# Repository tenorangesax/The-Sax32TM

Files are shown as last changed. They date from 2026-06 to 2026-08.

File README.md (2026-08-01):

# The-Sax32TM
This is a simple devboard utilizing the ESP32-S3-WROOM-1 chip. Designed by me to really understand how the ESP32 works and all those little components on the front do, while also giving me a little more experience with creating devboards now.  (Being displayed at Opensauce!)

**[THE WORKING VIDEO DEMO!!](https://youtu.be/G2ZkvX7cIcQ)**

**FINAL SHOTS:**




**3D VIEWER:**
[Sax32 BOM.csv](https://github.com/user-attachments/files/30619961/Sax32.BOM.csv)




**THE SCHEMATIC:**



**PCB EDITOR:**

Screenshot 2026-06-14 at 10 48 29 AM

**BOM:**

| Id | Designator | Footprint | Quantity | Comment | Supplier and ref |
|---:|---|---|---:|---|---|
| 1 | BOOT, RST | SW_Push_SPST_NO_Alps_SKRK | 2 | SW_SPST |  |
| 2 | C1, C4 | C_0603_1608Metric | 2 | 100nf |  |
| 3 | C2, C5 | C_0603_1608Metric | 2 | 10uf |  |
| 4 | C3 | C_0603_1608Metric | 1 | 22uf |  |
| 5 | D1 | LED_0603_1608Metric | 1 | RED |  |
| 6 | D2 | LED_0603_1608Metric | 1 | GREEN |  |
| 7 | D3 | LED_0603_1608Metric | 1 | BLUE |  |
| 8 | J1, J2 | PinHeader_1x20_P2.54mm_Vertical | 2 | Conn_01x20_Pin |  |
| 9 | J3 | USB_C_Receptacle_HRO_TYPE-C-31-M-12 | 1 | USB_C_Receptacle_USB2.0_16P |  |
| 10 | R1, R2, R3, R4, R5, R6 | R_0603_1608Metric | 6 | 5.1k |  |
| 11 | U1 | SOT-223-3_TabPin2 | 1 | LD1117S33TR_SOT223 |  |
| 12 | U3 | ESP32-S3-WROOM-1 | 1 | ESP32-S3-WROOM-1 |  |

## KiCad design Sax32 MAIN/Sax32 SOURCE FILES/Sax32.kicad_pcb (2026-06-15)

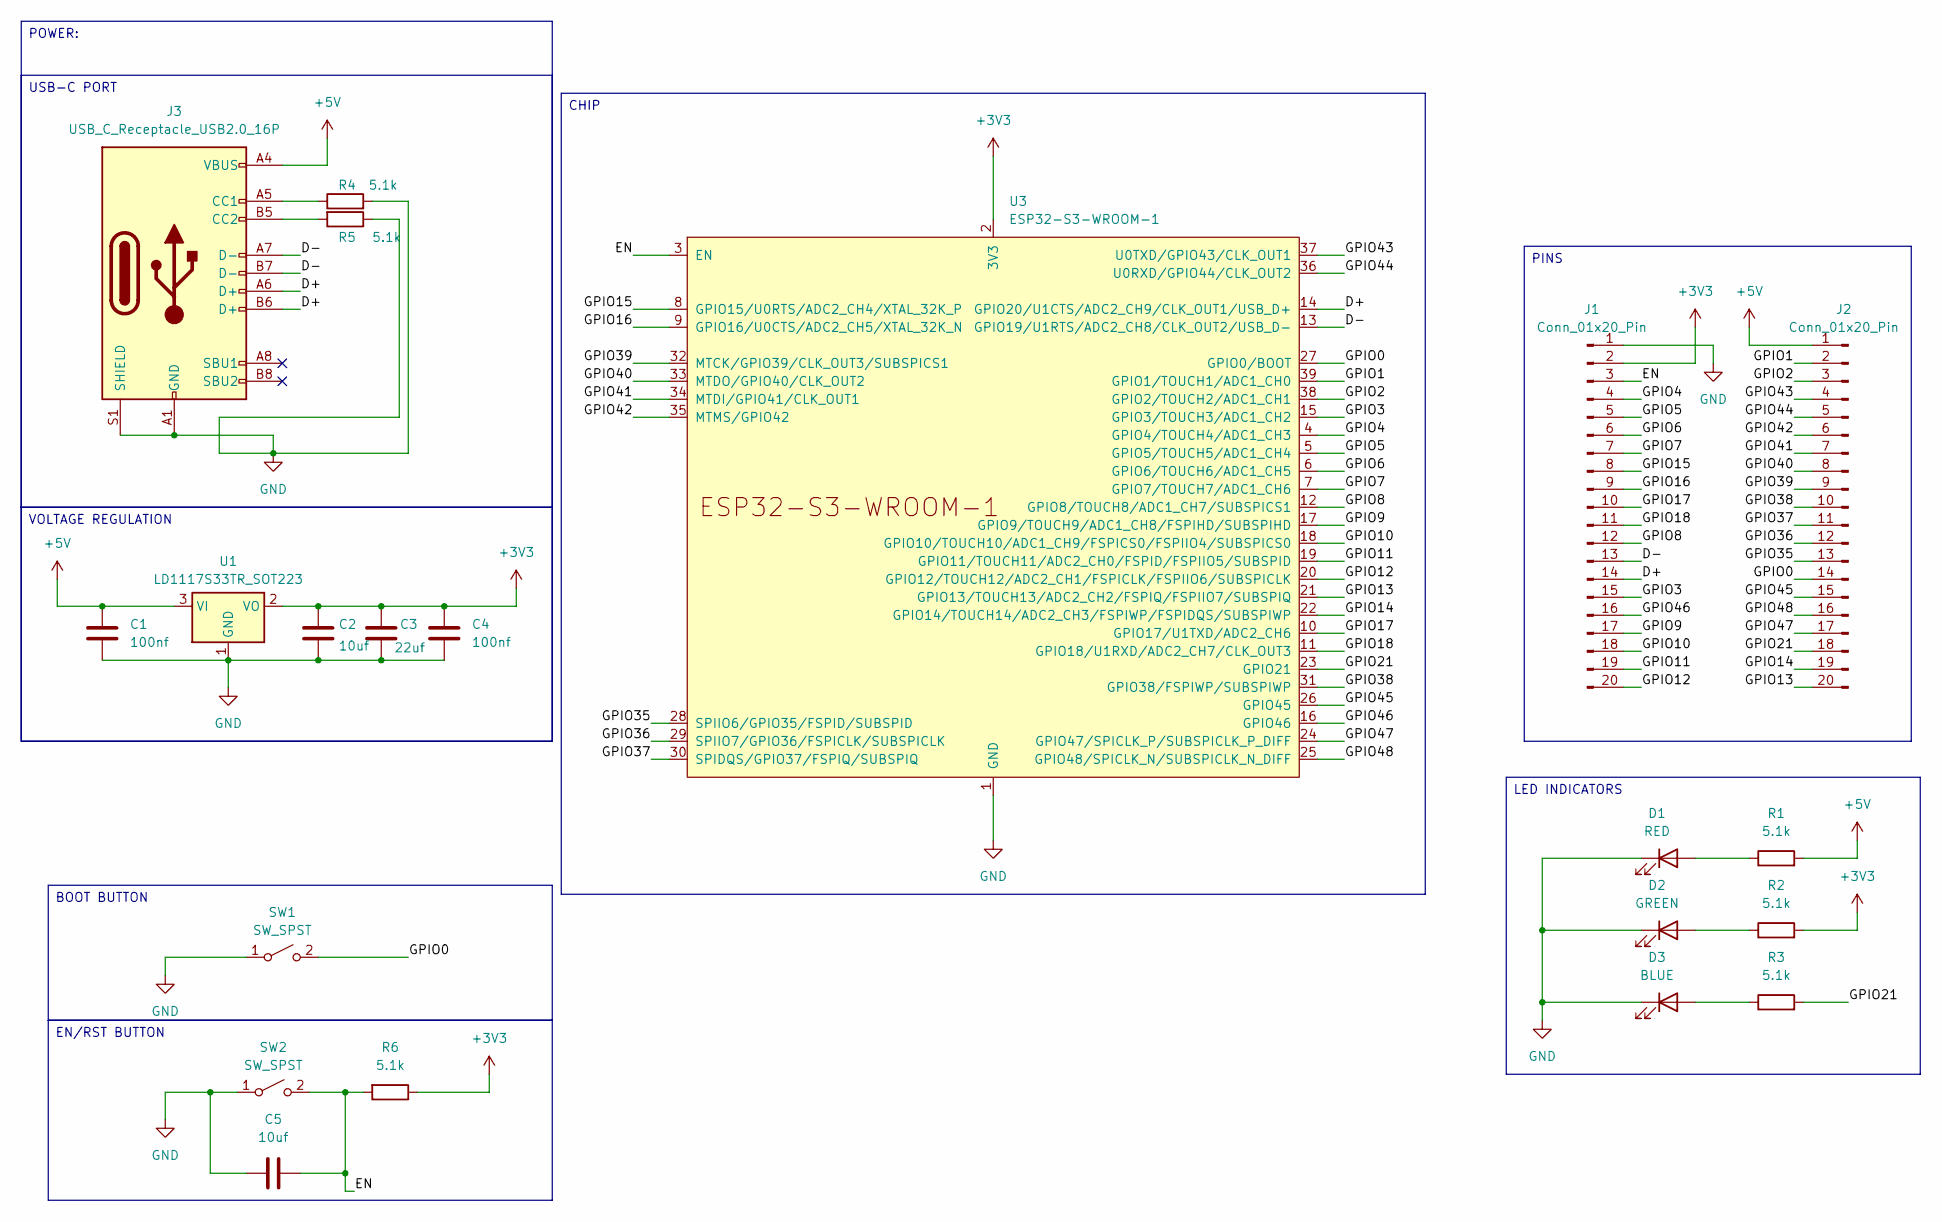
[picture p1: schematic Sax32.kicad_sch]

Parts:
C1, C4: 100nf; C_0603_1608Metric
C2, C5: 10uf; C_0603_1608Metric
C3: 22uf; C_0603_1608Metric
D1: RED; LED_0603_1608Metric
D2: GREEN; LED_0603_1608Metric
D3: BLUE; LED_0603_1608Metric
J1, J2: Conn_01x20_Pin; PinHeader_1x20_P2.54mm_Vertical
J3: USB_C_Receptacle_USB2.0_16P; USB_C_Receptacle_HRO_TYPE-C-31-M-12
R1, R2, R3, R4, R5, R6: 5.1k; R_0603_1608Metric
SW1, SW2: SW_SPST; SW_Push_SPST_NO_Alps_SKRK
U1: LD1117S33TR_SOT223; SOT-223-3_TabPin2
U3: ESP32-S3-WROOM-1

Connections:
+3V3: C2.1, C3.1, C4.1, J1.2, R2.2, R6.1, U1.2 (VO), U3.2 (3V3)
+5V: C1.1, J2.1, J3.A4 (VBUS), J3.A9 (VBUS), J3.B4 (VBUS), J3.B9 (VBUS), R1.2, U1.3 (VI)
/D+: J1.14, J3.A6 (D+), J3.B6 (D+), U3.14 (GPIO20/U1CTS/ADC2_CH9/CLK_OUT1/USB_D+)
/D-: J1.13, J3.A7 (D-), J3.B7 (D-), U3.13 (GPIO19/U1RTS/ADC2_CH8/CLK_OUT2/USB_D-)
/EN: C5.2, J1.3, R6.2, SW2.2 (B), U3.3 (EN); also elsewhere on the board
/GPIO0: J2.14, SW1.2 (B), U3.27 (GPIO0/BOOT); also elsewhere on the board
/GPIO1: J2.2, U3.39 (GPIO1/TOUCH1/ADC1_CH0)
/GPIO2: J2.3, U3.38 (GPIO2/TOUCH2/ADC1_CH1)
/GPIO3: J1.15, U3.15 (GPIO3/TOUCH3/ADC1_CH2)
/GPIO4: J1.4, U3.4 (GPIO4/TOUCH4/ADC1_CH3)
/GPIO5: J1.5, U3.5 (GPIO5/TOUCH5/ADC1_CH4)
/GPIO6: J1.6, U3.6 (GPIO6/TOUCH6/ADC1_CH5)
/GPIO7: J1.7, U3.7 (GPIO7/TOUCH7/ADC1_CH6)
/GPIO8: J1.12, U3.12 (GPIO8/TOUCH8/ADC1_CH7/SUBSPICS1)
/GPIO9: J1.17, U3.17 (GPIO9/TOUCH9/ADC1_CH8/FSPIHD/SUBSPIHD)
/GPIO10: J1.18, U3.18 (GPIO10/TOUCH10/ADC1_CH9/FSPICS0/FSPIIO4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)
/GPIO11: J1.19, U3.19 (GPIO11/TOUCH11/ADC2_CH0/FSPID/FSPIIO5/S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)
/GPIO12: J1.20, U3.20 (GPIO12/TOUCH12/ADC2_CH1/FSPICLK/FSPIIO6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)
/GPIO13: J2.20, U3.21 (GPIO13/TOUCH13/ADC2_CH2/FSPIQ/FSPIIO7/S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)
/GPIO14: J2.19, U3.22 (GPIO14/TOUCH14/ADC2_CH3/FSPIWP/FSPIDQS/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)
/GPIO15: J1.8, U3.8 (GPIO15/U0RTS/ADC2_CH4/XTAL_32K_P)
/GPIO16: J1.9, U3.9 (GPIO16/U0CTS/ADC2_CH5/XTAL_32K_N)
/GPIO17: J1.10, U3.10 (GPIO17/U1TXD/ADC2_CH6)
/GPIO18: J1.11, U3.11 (GPIO18/U1RXD/ADC2_CH7/CLK_OUT3)
/GPIO21: J2.18, R3.2, U3.23 (GPIO21)
/GPIO35: J2.13, U3.28 (SPIIO6/GPIO35/FSPID/SUBSPID)
/GPIO36: J2.12, U3.29 (SPIIO7/GPIO36/FSPICLK/SUBSPICLK)
/GPIO37: J2.11, U3.30 (SPIDQS/GPIO37/FSPIQ/SUBSPIQ)
/GPIO38: J2.10, U3.31 (GPIO38/FSPIWP/SUBSPIWP)
/GPIO39: J2.9, U3.32 (MTCK/GPIO39/CLK_OUT3/SUBSPICS1)
/GPIO40: J2.8, U3.33 (MTDO/GPIO40/CLK_OUT2)
/GPIO41: J2.7, U3.34 (MTDI/GPIO41/CLK_OUT1)
/GPIO42: J2.6, U3.35 (MTMS/GPIO42)
/GPIO43: J2.4, U3.37 (U0TXD/GPIO43/CLK_OUT1)
/GPIO44: J2.5, U3.36 (U0RXD/GPIO44/CLK_OUT2)
/GPIO45: J2.15, U3.26 (GPIO45)
/GPIO46: J1.16, U3.16 (GPIO46)
/GPIO47: J2.17, U3.24 (GPIO47/SPICLK_P/SUBSPICLK_P_DIFF)
/GPIO48: J2.16, U3.25 (GPIO48/SPICLK_N/SUBSPICLK_N_DIFF)
GND: C1.2, C2.2, C3.2, C4.2, C5.1, D1.1 (K), D2.1 (K), D3.1 (K), J1.1, J3.A1 (GND), J3.A12 (GND), J3.B1 (GND), J3.B12 (GND), J3.S1 (SHIELD), R4.2, R5.1, SW1.1 (A), SW2.1 (A), U1.1 (GND), U3.1 (GND), U3.40 (GND), U3.41 (GND); also elsewhere on the board
unnamed: D1.2 (A), R1.1
unnamed: D2.2 (A), R2.1
unnamed: D3.2 (A), R3.1
unnamed: J3.A5 (CC1), R4.1
unnamed: J3.B5 (CC2), R5.2

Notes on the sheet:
VOLTAGE REGULATION
PINS
POWER:
EN/RST BUTTON
LED INDICATORS
USB-C PORT
BOOT BUTTON
CHIP

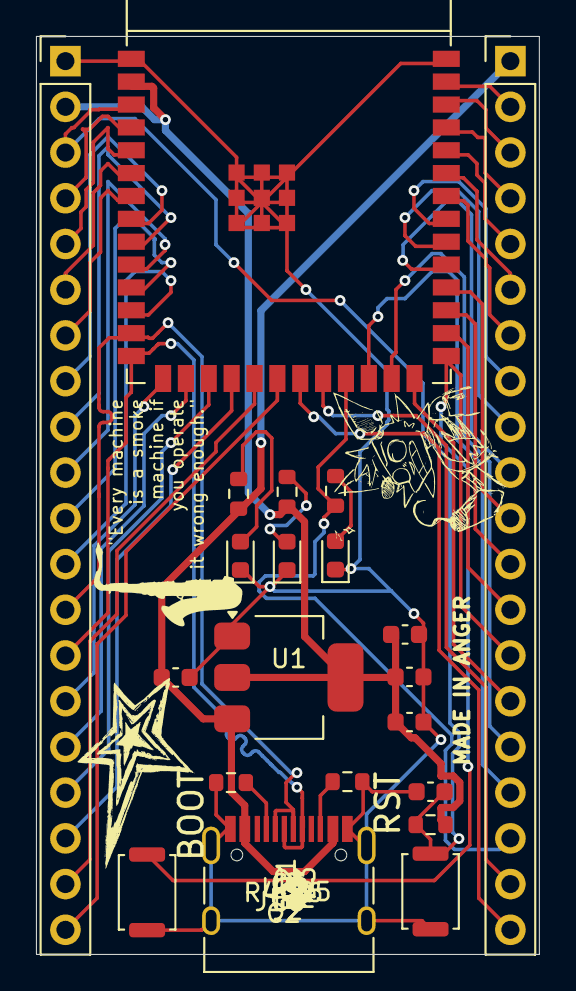
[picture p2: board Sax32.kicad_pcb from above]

Board: 2 copper layers, 27.9 x 51.0 mm, 21 parts (0 on the bottom side), 45 nets.

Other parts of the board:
BOOT: SW_SPST; SW_Push_SPST_NO_Alps_SKRK
RST: SW_SPST; SW_Push_SPST_NO_Alps_SKRK

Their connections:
/EN: RST.2 (B); also elsewhere on the board
/GPIO0: BOOT.2 (B); also elsewhere on the board
GND: BOOT.1 (A), RST.1 (A); also elsewhere on the board

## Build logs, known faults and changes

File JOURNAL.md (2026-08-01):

<!--
  This journal is auto generated by Stasis.
-->

# 7/12/2026 4 PM - SOLDERING AND FINISHING TOUCHES!

_Time spent: 3.5h_

My stuff finally arrived, so I could get to work! (at least most of them)

The devboard, S3 chips, (buttons I already had from previous projects) were here!

I did order a hotplate and some solder paste because in the center, there are these ground pins that I asked about, and apparently they are used
for cooling the chip.

While my hotplate wasn't there, I decided to hand solder a chip and buttons to see how it would go.

It was a little hard, but I got the hang of it and it became fun!

It also worked and I put thonny firmware on it.

When my hotplate did arrive though, I broke the stencil because my board was already populated with components, and i just needed the chip stencil to lay flat on the board.

Unfortuantely it didn't work and smeared all over the pins, so i just decided to put a glob all over it since the flux would guide it to the pads, which did work after I adjusted
the solder on the hot plate while it cooked.



Those boards also worked too, which was a success! I tested in thonny after.






































# 6/15/2026 2 AM - FINISHING UP AND REVIEWER SENDING TIME!!!

_Time spent: 2.75h_

Today I finished up the entire ordering process, and made sure to be able to get a good cost on everything to make it as cheap as possible.

Firstly, I put whatever I could in the PCBA assembly, mainly the LEDS, capacitors, resistors because I didn't want to do those tiny little connections, and had to find where the cheapest options were and making sure that they were the correct voltage and stuff.

The LEDS had to be comprimised, and I had to make 2 of them red and one white so I could do economic PCBA assembly for a low price.

In the 3D editor, I adjusted the parts, like the 1117 and USBC port and others to their correct positons/polarity.

I then had to find where the source of the ESP32-S3-WROOM-1-N16R2 Modules were being sold, got the amazon link after digging through the entire website, and added to cart.

The push buttons I already have at home from my last devboard, and I made sure to use the same footprint so I could cut costs.

I then set up the github and sent it on its way! 

Screenshot 2026-06-14 at 9.08.30 PM

Screenshot 2026-06-14 at 9.08.20 PM

Screenshot 2026-06-14 at 9.05.34 PM

Screenshot 2026-06-14 at 9.46.15 PM

Screenshot 2026-06-14 at 9.30.22 PM

I also got a stencil to solder it







# 6/14/2026 7 PM - PCB Design Finish

_Time spent: 5.75h_

First off, I assigned the footprints:

Screenshot 2026-06-13 at 6.50.39 PM

Obviously all SMD components and turtle buttons, with the same USBC port I used in my last devboard.

I used a reference for board sizes so that this looks and functions like a regular devboard, and have proper spacing using this chart I found online: 



Using this chart, I set the board size, spacing of pins, and more to be standard.

Screenshot 2026-06-13 at 8.13.01 PM

Then I made the power (3v3 and 5v) thicker than the other traces, made data transfer (d+,d-) the same skew.
Screenshot 2026-06-14 at 2.33.07 PM

Then I did the rest of the wiring and finished the other errors.

Screenshot 2026-06-14 at 10.48.29 AM

I then did the front and back silkscreen decorations.

Screenshot 2026-06-14 at 2.35.52 PM

Screenshot 2026-06-14 at 2.36.34 PM

I also asked in other servers for help and tips with the electronics. Kicad crashed a lot but I got it done.









# 6/13/2026 10 PM - Schematic + Project Start

_Time spent: 3.583333333333333h_

Today I started this project to learn more about how an ESP32 works, how it functions, and the basic requirements to get it running.

Here is the schematic I made:

Screenshot 2026-06-13 at 5.51.21 PM

The ESP32 I'm making uses a USB-C port with the data pins (D-, D+), the LD1117 (from the original ESP32) for regulating the voltage, then a button for BOOT and a button for EN (with an added capacitor and resistor for voltage stablization.

In the middle is the ESP32-S3-WROOM-1 chip, with WiFi and Bluetooth, and with its pins set up.

On the right is the pins (holes) for the ESP32, and below that is the LED indicators.

It is much more straightforward, and I used a lot of knowledge from my previous PI pico devboard.
